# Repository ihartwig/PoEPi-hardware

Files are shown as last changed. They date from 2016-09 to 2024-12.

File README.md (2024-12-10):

Raspberry Pi Zero PoE - PoEPi
=============================

This repository houses multiple designs for a PoE hat for RPi Zero that combines a 802.3af compliant controller with a 10Mbps ethernet controller/phy to provide power and connectivity over the same cable. The board shape matches RPi Zero, but this board should work on RPi 1/2/3 with 40-pin GPIO and the right headers. Footprints for the RPi Hat EEPROM are present but untested.

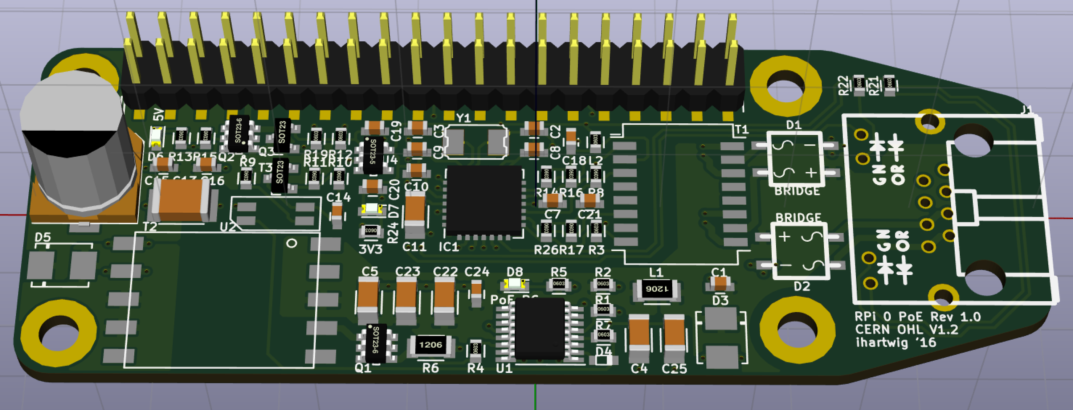
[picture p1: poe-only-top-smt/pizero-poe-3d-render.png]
PoEPi 3D render


## Features
* 5V 12.95W 802.3af-compliant PoE with LTC4267
* 10Mbps ethernet using ENC28J60 (includes Raspbian driver support)

## Variations

* **passive-poe-only-top-smt**: Schematic only (layout abandoned) for an FRC Passive PoE (4-18V) variant using a TPS63070 buck-boost regulator
  * Ported sch, pcb, and libs to KiCAD 7.0.2
  * New project at https://github.com/ihartwig/ether-friends/tree/main/pizero-papoe
* **poe-only-top-smt**: Rev 2 with only PoE parts and all parts on top for easy automated assembly.
  * [Order bare pcbs from Dirty PCB](http://dirtypcbs.com/view.php?share=26685&accesskey=).
  * Known issues:
    * J1 TPIN+/- pair is on the wrong pins - no link up
    * PoE negotiation does not complete
* **servo-controller**: Rev 1 with buffered output to drive 3 servos.
* **speaker-amplifier**: Rev 1 with an amplifier for the RPi's PWM audio output.
* **ws2812-controller**: Rev 1 with a connector for NeoPixels.

## Raspberry Pi Zero - PoEPi

The Raspberry Pi Zero is a low power and low footprint Raspberry Pi. It gives people an opportunity to move towards compact connected devices
while moving away from being a just a small computer. PiPoE adds a new way of connecting the Raspberry Pi Zero with the world in a very efficient
manner. Power over Ethernet is a way if injecting power into an Ethernet cable without interfering with the data. What it gives you is a high 
reliability way of powering and communicating with the Raspberry Pi. The design of PoEPi is open source under the CERN OHL V1.2 and can be easily
adapted to your own custom designs. 

For more information check out the Wiki on github

### Basic Hardware usage

1. Setup your Raspberry Pi with a monitor and enable SSH with raspi-config
2. Plug Ethernet cable into a PoE switch or add a PoE injector somehwhere in you Ethernet line
3. Connect the PoEPi to the Raspberry Pi
4. Plug in the "injected" Ethernet cable
5. The Pi Zero should be powered and you then SSH into the Pi

For information on the particular PoEPi modules and how to control them please see the wiki on the github page

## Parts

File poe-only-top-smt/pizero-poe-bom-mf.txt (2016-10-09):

Designator	X-Loc	Y-Loc	Rotation	Side	Type	X-Size	Y-Size	Value	Footprint	Populate	MPN
C1	55.5	-22.25	180	top	SMT	2	1	0.1uf 100V	Capacitors_SMD:C_0603	1	CL10B104KC8NNNC
C10	29.25	-12.25	180	top	SMT	2	1	0.1uf	Capacitors_SMD:C_0603	1	
C11	29.25	-16	90	top	SMT	2	1	10uf	Capacitors_SMD:C_1206	1	
C12	3.25	-14.25	270	top	SMT	2	1	470uF	Capacitors_SMD:c_elec_8x10	1	UWT1A471MNL1GS
C13	22	-12.5	0	top	SMT	2	1	2.2nF 250Vac	Capacitors_SMD:C_0603	1	C1608C0G2E222J080AA
C14	11.25	-15.25	90	top	SMT	2	1	6.8nf	Capacitors_SMD:C_0603	1	
C15	7.25	-15.25	270	top	SMT	2	1	0.1uF	Capacitors_SMD:C_0603	1	
C16	9.25	-15.25	270	top	SMT	2	1	0.1uF	Capacitors_SMD:C_0603	1	
C17	43.25	-8	0	bottom	nostuff	2	1	nostuff-0.1u	Capacitors_SMD:C_0603	0	
C18	42.75	-9	270	top	SMT	2	1	0.1uf	Capacitors_SMD:C_0603	1	
C19	16.75	-8.75	270	top	SMT	2	1	1uF	Capacitors_SMD:C_0603	1	
C2	40	-8	180	top	SMT	2	1	16pf	Capacitors_SMD:C_0603	1	
C20	22.75	-8.75	270	top	SMT	2	1	1uF	Capacitors_SMD:C_0603	1	
C21	44.25	-14.75	0	top	SMT	2	1	0.1uf	Capacitors_SMD:C_0603	1	
C22	33.75	-23.75	90	top	SMT	2	1	2.2uF 100V	Capacitors_SMD:C_1206	1	GRM31CR72A225KA73L
C23	30.75	-23.75	90	top	SMT	2	1	2.2uF 100V	Capacitors_SMD:C_1206	1	GRM31CR72A225KA73L
C24	36.25	-23	90	top	SMT	2	1	0.1uF 100V	Capacitors_SMD:C_0603	1	CL10B104KC8NNNC
C25	51.75	-27	270	top	SMT	2	1	2.2uF 100V	Capacitors_SMD:C_1206	1	GRM31CR72A225KA73L
C3	30.5	-8	0	top	SMT	2	1	16pf	Capacitors_SMD:C_0603	1	
C4	49	-27	270	top	SMT	2	1	2.2uF 100V	Capacitors_SMD:C_1206	1	GRM31CR72A225KA73L
C5	27.75	-23.75	90	top	SMT	2	1	2.2uF 100V	Capacitors_SMD:C_1206	1	GRM31CR72A225KA73L
C7	41.25	-14.75	0	top	SMT	2	1	0.1uf	Capacitors_SMD:C_0603	1	
C8	40	-10	0	top	SMT	2	1	0.1uf	Capacitors_SMD:C_0603	1	
C9	30.5	-10	180	top	SMT	2	1	0.1uf	Capacitors_SMD:C_0603	1	
D1	61.5	-11	0	top	SMT	2	1	BRIDGE	pizero-poe-special:MBS	1	HD01-T
D2	61.5	-18.5	180	top	SMT	2	1	BRIDGE	pizero-poe-special:MBS	1	HD01-T
D3	55.5	-26.75	270	top	SMT	2	1	SMAJ58A	Diodes_SMD:DO-214BA	1	SMAJ58A
D4	46.25	-28.75	0	top	SMT	2	1	BAS516	pizero-poe-special:sod523	1	"BAS516,115"
D5	3.25	-20.5	0	top	SMT	2	1	SBM1040	Diodes_SMD:DO-214BA	1	RB058L150TE25
D6	1.25	-8.75	270	top	SMT	2	1	LED Green	LEDs:LED_0603	1	LTST-C190GKT
D7	24.75	-8.75	90	top	SMT	2	1	LED Green	LEDs:LED_0603	1	LTST-C190GKT
D8	39.25	-22.25	180	top	SMT	2	1	LED Green	LEDs:LED_0603	1	LTST-C190GKT
IC1	35.25	-14.75	90	top	SMT	2	1	ENC28J60-I/ML	Housings_DFN_QFN:QFN-28-1EP_6x6mm_Pitch0.65mm	1	ENC28J60-I/ML
J1					nostuff	2	1	RJ45-LED	w_conn_pc:rj45-tyco-2-406549-7	0	RJHSE-5081
L1	50.5	-22.75	180	top	SMT	2	1	2.2uH	Resistors_SMD:R_1206	1	LQM2HPN2R2MEHL
L2	44.75	-9	90	top	SMT	2	1	BEAD	Resistors_SMD:R_0603	1	
P2					nostuff	2	1	dnp-REF-182665-01	pizero-poe-special:Pin_Header_Straight_TH-SMT-NoPaste_2x20	0	
Q1	28.5	-27.75	0	top	SMT	2	1	SI3440DV	TO_SOT_Packages_SMD:SOT-23-6	1	SI3440DV-T1-E3
Q2	8.25	-8.75	180	top	SMT	2	1	DMMT3906_Dual_PNP	TO_SOT_Packages_SMD:SOT-23-6	1	DMMT3906-7-F
Q3	12	-8.75	180	top	SMT	2	1	Q_PMOS_GSD	TO_SOT_Packages_SMD:SOT-23	1	DMP3099L-7
R1	46.25	-24.5	0	top	nostuff	2	1	nostuff	Resistors_SMD:R_0603	0	
R10	11.25	-12	270	top	SMT	2	1	10k	Resistors_SMD:R_0603	1	
R11	7.25	-12	270	top	SMT	2	1	10k	Resistors_SMD:R_0603	1	
R12	9.25	-12	90	top	SMT	2	1	3.3k	Resistors_SMD:R_0603	1	
R13	3.25	-8.75	270	top	SMT	2	1	1k	Resistors_SMD:R_0603	1	
R14	40.75	-12.25	270	top	SMT	2	1	49.9	Resistors_SMD:R_0603	1	
R15	5.25	-8.75	270	top	SMT	2	1	10k	Resistors_SMD:R_0603	1	
R16	42.75	-12.25	270	top	SMT	2	1	49.9	Resistors_SMD:R_0603	1	
R17	42.75	-17.25	270	top	SMT	2	1	49.9	Resistors_SMD:R_0603	1	
R18	37.75	-8	0	bottom	nostuff	2	1	nostuff-1k	Resistors_SMD:R_0603	0	
R19	14.75	-8.75	270	top	SMT	2	1	47k	Resistors_SMD:R_0603	1	
R2	46.25	-22.25	0	top	SMT	2	1	10k	Resistors_SMD:R_0603	1	
R20	37.75	-12	0	bottom	nostuff	2	1	nostuff-3.9k	Resistors_SMD:R_0603	0	
R21	70	-3.5	90	top	SMT	2	1	549	Resistors_SMD:R_0603	1	
R22	67.5	-3.5	90	top	SMT	2	1	549	Resistors_SMD:R_0603	1	
R23	37.75	-10	0	bottom	nostuff	2	1	nostuff-3.9k	Resistors_SMD:R_0603	0	
R24	26.75	-8.75	90	top	SMT	2	1	220	Resistors_SMD:R_0603	1	
R26	40.75	-17.25	270	top	SMT	2	1	49.9	Resistors_SMD:R_0603	1	
R3	44.75	-17.25	90	top	SMT	2	1	1k	Resistors_SMD:R_0603	1	
R4	36.25	-28	90	top	SMT	2	1	10k	Resistors_SMD:R_0603	1	
R5	42.75	-22.25	0	top	SMT	2	1	23k	Resistors_SMD:R_0603	1	
R6	32.75	-27.75	0	top	SMT	2	1	0.05	Resistors_SMD:R_1206	1	CSNL1206FT50L0
R7	46.25	-26.75	0	top	SMT	2	1	6.8k	Resistors_SMD:R_0603	1	
R8	44.75	-12.25	270	top	SMT	2	1	2.32k	Resistors_SMD:R_0603	1	
R9	13.25	-12	270	top	SMT	2	1	1k	Resistors_SMD:R_0603	1	
T1	51.5	-13.75	0	top	SMT	2	1	H2019FNL	pizero-poe-special:Transformer_Pulse_H2019FNL	1	749013011A
T2	16.75	-23.5	90	top	SMT	2	1	TRANSFO	project_foot:PoE_TRANS	1	7491199501
T3	14	-15.25	90	top	SMT	2	1	VOLTAGE_REF	TO_SOT_Packages_SMD:SOT-23	1	TLV431BSN1T1G
U1	41.25	-26.5	180	top	SMT	2	1	LTC4267	Housings_SSOP:QSOP-16_3.9x4.9mm_Pitch0.635mm	1	LTC4267CGN#PBF
U2	20.5	-15.25	270	top	SMT	2	1	PS2911-1-K-AX	project_foot:OPTO_ISO	1	PS2911-1-K-AX
U3	43.25	-11	180	bottom	nostuff	2	1	nostuff-AT24CS32-SSHM	Housings_SSOP:TSSOP-8_4.4x3mm_Pitch0.65mm	0	
U4	19.75	-8.75	0	top	SMT	2	1	AP7365_SOT-23-5	TO_SOT_Packages_SMD:SOT-23-5	1	AP7365-33WG-7
W1					nostuff	2	1	TEST_1P	Measurement_Points:Measurement_Point_Round-SMD-Pad_Small	0	
W2					nostuff	2	1	TEST_1P	Measurement_Points:Measurement_Point_Round-SMD-Pad_Small	0	
Y1	35.25	-9	180	top	SMT	2	1	25Mhz	w_crystal:crystal_smd_5x3.2mm	1	445I23D25M00000

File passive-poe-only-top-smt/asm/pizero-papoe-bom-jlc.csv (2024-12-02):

Comment | Designator | Footprint | LCSC
0.1uf 100V | C1 | Capacitor_SMD:C_0603_1608Metric
10uf | C11 | Capacitor_SMD:C_1206_3216Metric
470uF | C12 | Capacitor_SMD:CP_Elec_8x10
0.1uF | C15,C16 | Capacitor_SMD:C_0603_1608Metric
nostuff-0.1u | C17 | Capacitor_SMD:C_0603_1608Metric
1uF | C19,C20 | Capacitor_SMD:C_0603_1608Metric
16pf | C2,C3 | Capacitor_SMD:C_0603_1608Metric
0.1uf | C7,C8,C9,C10,C18,C21 | Capacitor_SMD:C_0603_1608Metric
BRIDGE | D1,D2 | pizero-poe-special:MBS | C52151
SMAJ58A | D3 | Diode_SMD:D_SMA
LED Green | D6,D7 | LED_SMD:LED_0603_1608Metric
hole-metalized-no4 | H1,H2,H3,H4 | pizero-poe-special:hole-m3
RJ45-LED | J1 | pizero-poe-special:rj45-tyco-2-406549-7
1.5uH 4.6A Isat | L1
BEAD | L2 | Resistor_SMD:R_0603_1608Metric
dnp-REF-182665-01 | P2 | pizero-poe-special:Pin_Header_Straight_TH-SMT-NoPaste_2x20
DMMT3906_Dual_PNP | Q2 | Package_TO_SOT_SMD:SOT-23-6 | C526572
Q_PMOS_GSD | Q3 | Package_TO_SOT_SMD:SOT-23 | C155244
R_Small | R1,R2,R4,R5
49.9 | R14,R16,R17,R26 | Resistor_SMD:R_0603_1608Metric
10k | R15 | Resistor_SMD:R_0603_1608Metric
nostuff-1k | R18 | Resistor_SMD:R_0603_1608Metric
47k | R19 | Resistor_SMD:R_0603_1608Metric
nostuff-3.9k | R20,R23 | Resistor_SMD:R_0603_1608Metric
549 | R21,R22 | Resistor_SMD:R_0603_1608Metric
220 | R24 | Resistor_SMD:R_0603_1608Metric
1k | R3,R13 | Resistor_SMD:R_0603_1608Metric
2.32k | R8 | Resistor_SMD:R_0603_1608Metric
H2019FNL | T1 | pizero-poe-special:Transformer_Pulse_H2019FNL | C7193798
ENC28J60-I/ML | U1 | Package_DFN_QFN:QFN-28-1EP_6x6mm_P0.65mm_EP4.25x4.25mm | C629417
TPS63070RNMR | U2 | TPS63070RNMR:VREG_TPS63070RNMR | C109322
nostuff-AT24CS32-SSHM | U3 | Package_SO:TSSOP-8_4.4x3mm_P0.65mm
AP7365_SOT-23-5 | U4 | Package_TO_SOT_SMD:SOT-23-5 | C150742
TEST_1P | W1,W2 | TestPoint:TestPoint_Pad_D1.0mm
25Mhz | Y1 | Crystal:Crystal_SMD_5032-2Pin_5.0x3.2mm

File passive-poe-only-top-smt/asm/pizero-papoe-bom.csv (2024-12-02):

Source: | /Users/ihartwig/repos/PoEPi-hardware/passive-poe-only-top-smt/pizero-papoe.kicad_sch
Date: | 2024 December 01, Sunday 01:49:08
Tool: | Eeschema 7.0.2-0
Generator: | /Applications/KiCad-7/KiCad.app/Contents/SharedSupport/plugins/bom_csv_grouped_by_value.py
Component Count: | 53
Collated Components:
Item | Qty | Reference(s) | Value | LibPart | Footprint | Datasheet | DNP | Alt Mfg | Alt Mfg Part No | Availability | Check_prices | Description | Digikey Part No | MANUFACTURER | MF | MP | Mfg | Mfg Part No | Mouser Part No. | PARTREV | Package | Price | STANDARD | SnapEDA_Link | Type
1 | 1 | C1 | 0.1uf 100V | pizero-papoe-rescue:C | Capacitor_SMD:C_0603_1608Metric |  |  |  |  |  |  | 0.10µF 100V Ceramic Capacitor X7R 0603 | 1276-6807-1-ND |  |  |  | Samsung | CL10B104KC8NNNC |  |  |  |  |  |  | SMT
2 | 2 | C2, C3 | 16pf | pizero-papoe-rescue:C | Capacitor_SMD:C_0603_1608Metric |  |  |  |  |  |  |  |  |  |  |  |  |  |  |  |  |  |  |  | SMT
3 | 6 | C7, C8, C9, C10, C18, C21 | 0.1uf | pizero-papoe-rescue:C | Capacitor_SMD:C_0603_1608Metric |  |  |  |  |  |  |  |  |  |  |  |  |  |  |  |  |  |  |  | SMT
4 | 1 | C11 | 10uf | pizero-papoe-rescue:C | Capacitor_SMD:C_1206_3216Metric |  |  |  |  |  |  |  |  |  |  |  |  |  |  |  |  |  |  |  | SMT
5 | 1 | C12 | 470uF | pizero-papoe-rescue:CP | Capacitor_SMD:CP_Elec_8x10 |  |  |  |  |  |  | 470µF 10V Aluminum Capacitors Radial, Can - SMD | 493-2169-1-ND |  |  |  | Nichicon | UWT1A471MNL1GS |  |  |  |  |  |  | SMT
6 | 2 | C15, C16 | 0.1uF | pizero-papoe-rescue:C | Capacitor_SMD:C_0603_1608Metric |  |  |  |  |  |  |  |  |  |  |  |  |  |  |  |  |  |  |  | SMT
7 | 1 | C17 | nostuff-0.1u | pizero-papoe-rescue:C_Small | Capacitor_SMD:C_0603_1608Metric |  |  |  |  |  |  |  |  |  |  |  |  |  |  |  |  |  |  |  | nostuff
8 | 2 | C19, C20 | 1uF | pizero-papoe-rescue:C_Small | Capacitor_SMD:C_0603_1608Metric |  |  |  |  |  |  |  |  |  |  |  |  |  |  |  |  |  |  |  | SMT
9 | 2 | D1, D2 | BRIDGE | pizero-papoe-rescue:BRIDGE | pizero-poe-special:MBS |  |  |  |  |  |  | Bridge Rectifier Single Phase 100V 800mA Surface Mount 4-MiniDIP | HD01DICT-ND |  |  |  | Diodes Inc | HD01-T |  |  |  |  |  |  | SMT
10 | 1 | D3 | SMAJ58A | pizero-papoe-rescue:ZENER | Diode_SMD:D_SMA |  |  |  |  |  |  | TVS DIODE 58VWM 93.6VC SMA | SMAJ58ALFCT-ND |  |  |  | Littelfuse | SMAJ58A | 576-SMAJ58A |  |  |  |  |  | SMT
11 | 2 | D6, D7 | LED Green | pizero-papoe-rescue:Led_Small | LED_SMD:LED_0603_1608Metric |  |  |  |  |  |  | LED GREEN CLEAR 0603 SMD | 160-1183-1-ND |  |  |  | Lite-On | LTST-C190GKT |  |  |  |  |  |  | SMT
12 | 4 | H1, H2, H3, H4 | hole-metalized-no4 | pizero-papoe-rescue:hole-metalized-no4 | pizero-poe-special:hole-m3 |  |  |  |  |  |  |  |  |  |  |  |  |  |  |  |  |  |  |  | nostuff
13 | 1 | J1 | RJ45-LED | pizero-papoe-rescue:RJ45-LED | pizero-poe-special:rj45-tyco-2-406549-7 |  |  |  |  |  |  | Jack Modular Connector 8p8c (RJ45, Ethernet) 90° Angle (Right) Unshielded | RJHSE-5081-ND |  |  |  | Amphenol | RJHSE-5081 |  |  |  |  |  |  | TH
14 | 1 | L2 | BEAD | pizero-papoe-rescue:INDUCTOR | Resistor_SMD:R_0603_1608Metric |  |  |  |  |  |  | FERRITE BEAD 1 KOHM 0603 1LN | 587-1867-1-ND |  |  |  | Taiyo Yuden | BK1608HS102-T |  |  |  |  |  |  | SMT
15 | 1 | P2 | dnp-REF-182665-01 | pizero-papoe-rescue:CONN_02X20 | pizero-poe-special:Pin_Header_Straight_TH-SMT-NoPaste_2x20 |  |  |  |  |  |  |  |  |  |  |  |  |  |  |  |  |  |  |  | nostuff
16 | 1 | Q2 | DMMT3906_Dual_PNP | pizero-papoe-rescue:DMMT3906_Dual_PNP | Package_TO_SOT_SMD:SOT-23-6 |  |  |  |  |  |  | TRANS 2PNP 40V 0.2A SOT26 | DMMT3906-7-FDICT-ND |  |  |  | Diodes Inc | DMMT3906-7-F |  |  |  |  |  |  | SMT
17 | 1 | Q3 | Q_PMOS_GSD | pizero-papoe-rescue:Q_PMOS_GSD | Package_TO_SOT_SMD:SOT-23 |  |  |  |  |  |  | MOSFET P-CH 30V SOT23 | DMP3099L-7DICT-ND |  |  |  | Diodes Inc | DMP3099L-7 |  |  |  |  |  |  | SMT
18 | 1 | R3 | 1k | pizero-papoe-rescue:R | Resistor_SMD:R_0603_1608Metric |  |  |  |  |  |  |  |  |  |  |  |  |  |  |  |  |  |  |  | SMT
19 | 1 | R8 | 2.32k | pizero-papoe-rescue:R | Resistor_SMD:R_0603_1608Metric |  |  |  |  |  |  |  |  |  |  |  |  |  |  |  |  |  |  |  | SMT
20 | 1 | R13 | 1k | pizero-papoe-rescue:R_Small | Resistor_SMD:R_0603_1608Metric |  |  |  |  |  |  |  |  |  |  |  |  |  |  |  |  |  |  |  | SMT
21 | 4 | R14, R16, R17, R26 | 49.9 | pizero-papoe-rescue:R | Resistor_SMD:R_0603_1608Metric |  |  |  |  |  |  |  |  |  |  |  |  |  |  |  |  |  |  |  | SMT
22 | 1 | R15 | 10k | pizero-papoe-rescue:R_Small | Resistor_SMD:R_0603_1608Metric |  |  |  |  |  |  |  |  |  |  |  |  |  |  |  |  |  |  |  | SMT
23 | 1 | R18 | nostuff-1k | pizero-papoe-rescue:R_Small | Resistor_SMD:R_0603_1608Metric |  |  |  |  |  |  |  |  |  |  |  |  |  |  |  |  |  |  |  | nostuff
24 | 1 | R19 | 47k | pizero-papoe-rescue:R_Small | Resistor_SMD:R_0603_1608Metric |  |  |  |  |  |  |  |  |  |  |  |  |  |  |  |  |  |  |  | SMT
25 | 2 | R20, R23 | nostuff-3.9k | pizero-papoe-rescue:R_Small | Resistor_SMD:R_0603_1608Metric |  |  |  |  |  |  |  |  |  |  |  |  |  |  |  |  |  |  |  | nostuff
26 | 2 | R21, R22 | 549 | pizero-papoe-rescue:R | Resistor_SMD:R_0603_1608Metric |  |  |  |  |  |  |  |  |  |  |  |  |  |  |  |  |  |  |  | SMT
27 | 1 | R24 | 220 | pizero-papoe-rescue:R_Small | Resistor_SMD:R_0603_1608Metric |  |  |  |  |  |  |  |  |  |  |  |  |  |  |  |  |  |  |  | SMT
28 | 1 | T1 | H2019FNL | pizero-papoe-rescue:H2019FNL | pizero-poe-special:Transformer_Pulse_H2019FNL |  |  | Pulse Electronics | H2019FNL |  |  | TRANS WE-LAN 10/100 POE SMD | 732-7063-1-ND |  |  |  | Wurth Electronics Inc | 749013011A |  |  |  |  |  |  | SMT
29 | 1 | U1 | ENC28J60-I/ML | pizero-papoe-rescue:ENC28J60-I/ML | Package_DFN_QFN:QFN-28-1EP_6x6mm_P0.65mm_EP4.25x4.25mm |  |  |  |  |  |  |  | ENC28J60-I/ML-ND |  |  |  | Microchip Technology | ENC28J60-I/ML |  |  |  |  |  |  | SMT
30 | 1 | U2 | ISL85410FRZ-T | pizero-papoe-special:ISL85410FRZ-T | pizero-poe-special:ISL85410FRZ-T_SON50P300X300X100-13N_270X200_ |  |  |  |  | In Stock | https://www.snapeda.com/parts/ISL85410FRZ-T/Intersil/view-part/?ref=eda | Buck Switching Regulator IC Positive Adjustable 0.6V 1 Output 1A 12-VFDFN Exposed Pad |  | RENESAS | Intersil | ISL85410FRZ-T |  |  |  | 8.00 | DFN-12 Intersil | None | IPC-7351B | https://www.snapeda.com/parts/ISL85410FRZ-T/Intersil/view-part/?ref=snap
31 | 1 | U3 | nostuff-AT24CS32-SSHM | pizero-papoe-rescue:AT24CS32-SSHM | Package_SO:TSSOP-8_4.4x3mm_P0.65mm |  |  |  |  |  |  |  |  |  |  |  |  |  |  |  |  |  |  |  | nostuff
32 | 1 | U4 | AP7365_SOT-23-5 | pizero-papoe-rescue:AP7365_SOT-23-5 | Package_TO_SOT_SMD:SOT-23-5 |  |  |  |  |  |  | Linear Voltage Regulator IC Positive Fixed 1 Output 3.3V 600mA SOT-25 | AP7365-33WG-7DICT-ND |  |  |  | Diodes Inc | AP7365-33WG-7 |  |  |  |  |  |  | SMT
33 | 2 | W1, W2 | TEST_1P | pizero-papoe-rescue:TEST_1P | TestPoint:TestPoint_Pad_D1.0mm |  |  |  |  |  |  |  |  |  |  |  |  |  |  |  |  |  |  |  | nostuff
34 | 1 | Y1 | 25Mhz | pizero-papoe-rescue:Crystal | Crystal:Crystal_SMD_5032-2Pin_5.0x3.2mm |  |  |  |  |  |  |  | CTX1175CT-ND |  |  |  | CTS Frequency Controls | 445I23D25M00000 | 774-445I23D25M00000 |  |  |  |  |  | SMT

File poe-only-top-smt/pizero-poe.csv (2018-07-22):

Component | Description | Part | References | Value | Footprint | Quantity Per PCB | Datasheet | Type | Digikey Part No | Mfg | Mfg Part No | Alt Mfg | Alt Mfg Part No | Mouser Part No.
1 | Unpolarized capacitor | C | C7 C8 C9 C10 C15 C16 C18 C21 | 0.1uf | C_0603 | 8 |  | SMT | 311-1088-1-ND
2 | Unpolarized capacitor | C | C1 C24 | 0.1uf 100V | C_0603 | 2 |  | SMT | 1276-6807-1-ND | Samsung | CL10B104KC8NNNC
3 | Unpolarized capacitor | C | C11 | 10uf | C_1206 | 1 |  | SMT | 311-2007-1-ND
4 | Unpolarized capacitor | C | C2 C3 | 16pf | C_0603 | 2 |  | SMT | 490-1408-1-ND
5 | Unpolarized capacitor | C_Small | C19 C20 | 1uF | C_0603 | 2 |  | SMT | 490-1536-1-ND
6 | Unpolarized capacitor | C | C13 | 2.2nF 250Vac | C_1812 | 1 |  | SMT | 490-3492-1-ND | Murata | GA343QR7GD222KW01L | Wurth Electronics | 8.85362E+11
7 | Unpolarized capacitor | C | C4 C5 C22 C23 C25 | 2.2uF 100V | C_1206 | 5 |  | SMT | 490-7209-1-ND | Murata Electronics | GRM31CR72A225KA73L
8 | Polarised capacitor | CP | C12 | 470uF | c_elec_8x10 | 1 |  | SMT | 493-2169-1-ND | Nichicon | UWT1A471MNL1GS
9 | Unpolarized capacitor | C | C14 | 6.8nf | C_0603 | 1 |  | SMT | 1276-1185-1-ND
10 | Unpolarized capacitor | C_Small | C17 | nostuff-0.1u | C_0603 | 1 |  | nostuff
11 |  | DIODE | D4 | BAS516 | sod523 | 1 |  | SMT | 568-1603-1-ND | NXP Semiconductors | BAS516,115 |  |  | 771-BAS516-T/R
12 |  | BRIDGE | D1 D2 | BRIDGE | MBS | 2 |  | SMT | HD01DICT-ND | Diodes Inc | HD01-T
13 | Led | Led_Small | D6 D7 D8 | LED Green | LED_0603 | 3 |  | SMT | 160-1183-1-ND | Lite-On | LTST-C190GKT
14 | Diode schottky | D_Schottky | D5 | SBM1040 | DO-214BA | 1 |  | SMT | RB058L150TE25CT-ND | Rohm Semiconductor | RB058L150TE25
15 | Diode zener | ZENER | D3 | SMAJ58A | DO-214BA | 1 |  | SMT | SMAJ58ALFCT-ND | Littelfuse | SMAJ58A |  |  | 576-SMAJ58A
16 |  | hole-metalized-no4 | H1 H2 H3 H4 | hole-metalized-no4 | hole-m3 | 4 |  | nostuff
17 | ENC28J60 Single Chip Ethernet Interface, QFN-28+EP | ENC28J60-I/ML | IC1 | ENC28J60-I/ML | QFN-28-1EP_6x6mm_Pitch0.65mm | 1 | http://ww1.microchip.com/downloads/en/devicedoc/39662a.pdf | SMT | ENC28J60-I/ML-ND | Microchip Technology | ENC28J60-I/ML
18 |  | RJ45-LED | J1 | RJ45-LED | rj45-tyco-2-406549-7 | 1 |  | TH | RJHSE-5081-ND | Amphenol | RJHSE-5081
19 |  | INDUCTOR | L1 | 2.2uH | R_1206 | 1 |  | SMT | 490-10966-1-ND | Murata Electronics | LQM2HPN2R2MEHL |  |  | 81-LQM2HPN2R2MEHL
20 |  | INDUCTOR | L2 | BEAD | R_0603 | 1 |  | SMT | 587-1867-1-ND | Taiyo Yuden | BK1608HS102-T
21 | Connector 02x20 | CONN_02X20 | P2 | dnp-REF-182665-01 | Pin_Header_Straight_TH-SMT-NoPaste_2x20 | 1 |  | nostuff
22 |  | DMMT3906_Dual_PNP | Q2 | DMMT3906_Dual_PNP | SOT-23-6 | 1 |  | SMT | DMMT3906-7-FDICT-ND | Diodes Inc | DMMT3906-7-F
23 | Transistor P-MOSFET (general) | Q_PMOS_GSD | Q3 | Q_PMOS_GSD | SOT-23 | 1 |  | SMT | DMP3099L-7DICT-ND | Diodes Inc | DMP3099L-7
24 |  | SI3440DV | Q1 | SI3440DV | SOT-23-6 | 1 |  | SMT | SI3440DV-T1-E3CT-ND | Vishay Siliconix | SI3440DV-T1-E3 |  |  | 781-SI3440DV-E3
25 | Resistor | R | R6 | 0.05 | R_1206 | 1 |  | SMT | CSNL1206FT50L0CT-ND | Stackpole Electronics | CSNL1206FT50L0 |  |  | 660-UR732BTTD50L0F
26 | Resistor | R | R2 R4 R10 R11 R15 | 10k | R_0603 | 5 |  | SMT | 311-10.0KHRCT-ND
27 | Resistor | R | R3 R9 R13 | 1k | R_0603 | 3 |  | SMT | 311-1.00KHRCT-ND
28 | Resistor | R | R8 | 2.32k | R_0603 | 1 |  | SMT | 311-2.32KHRCT-ND
29 | Resistor | R_Small | R24 | 220 | R_0603 | 1 |  | SMT | 311-220GRCT-ND
30 | Resistor | R_Small | R5 | 23k | R_0603 | 1 |  | SMT | 311-22KGRCT-ND
31 | Resistor | R | R12 | 3.3k | R_0603 | 1 |  | SMT | 311-3.3KGRCT-ND
32 | Resistor | R_Small | R19 | 47k | R_0603 | 1 |  | SMT | 311-47.0KHRCT-ND
33 | Resistor | R | R14 R16 R17 R26 | 49.9 | R_0603 | 4 |  | SMT | 311-49.9HRCT-ND
34 | Resistor | R | R21 R22 | 549 | R_0603 | 2 |  | SMT | 311-560GRCT-ND
35 | Resistor | R | R7 | 6.8k | R_0603 | 1 |  | SMT | 311-6.8KGRCT-ND
36 | Resistor | R_Small | R18 | nostuff-1k | R_0603 | 1 |  | nostuff
37 | Resistor | R_Small | R20 R23 | nostuff-3.9k | R_0603 | 2 |  | nostuff
38 |  | H2019FNL | T1 | H2019FNL | Transformer_Pulse_H2019FNL | 1 |  | SMT | 732-7063-1-ND | Wurth Electronics Inc | 749013011A | Pulse Electronics | H2019FNL
39 |  | POE_TRANS | T2 | TRANSFO | PoE_TRANS | 1 |  | SMT | 553-1983-1-ND | Pulse Electronics | PA1137NLT | Wurth Electronics Inc | 7491199501 | 710-7491199501
40 |  | VOLTAGE_REF | T3 | VOLTAGE_REF | SOT-23 | 1 |  | SMT | TLV431BSN1T1GOSCT-ND | ON Semiconductor | TLV431BSN1T1G |  |  | 863-TLV431BSN1T1G
41 |  | AP7365_SOT-23-5 | U4 | AP7365_SOT-23-5 | SOT-23-5 | 1 |  | SMT | AP7365-33WG-7DICT-ND | Diodes Inc | AP7365-33WG-7
42 |  | LTC4267 | U1 | LTC4267 | QSOP-16_3.9x4.9mm_Pitch0.635mm | 1 |  | SMT | LTC4267CGN-3#PBF-ND | Linear Technology | LTC4267CGN#PBF
43 | MFP 4L, Full Pitch Mini-Flat Random Phase Opto-Triac, Vdrm 250V, Ift 10mA | FODM3012 | U2 | PS2911-1-K-AX | OPTO_ISO | 1 | http://www.fairchildsemi.com/ds/FO/FODM3053.pdf | SMT | PS2911-1-K-AX-ND | CEL | PS2911-1-K-AX |  |  | 551-PS2911-1-K-AX
44 | 32Kb (4096x8) Serial EEPROM with Unique Serial Number, SO8 | AT24CS32-SSHM | U3 | nostuff-AT24CS32-SSHM | TSSOP-8_4.4x3mm_Pitch0.65mm | 1 | http://www.atmel.com/Images/Atmel-8869-SEEPROM-AT24CS32-Datasheet.pdf | nostuff
45 | point | TEST_1P | W1 W2 | TEST_1P | Measurement_Point_Round-SMD-Pad_Small | 2 |  | nostuff
46 | Two pin crystal | Crystal | Y1 | 25Mhz | crystal_smd_5x3.2mm | 1 |  | SMT | CTX1175CT-ND | CTS Frequency Controls | 445I23D25M00000 |  |  | 774-445I23D25M00000
Component Groups: | 47
Component Count: | 79
Fitted Components: | 78
Number of PCBs: | 1
Total components: | 78
Schematic Version: | 0.1d
Schematic Date: | 2/2/16
BoM Date: | Tuesday, October 25, 2016 'PMt' 10:26:28 PM
Schematic Source: | /Users/ihartwig/repos/PoEPi-hardware/poe-only-top-smt/pizero-poe.sch
KiCad Version: | Eeschema 4.0.2-stable

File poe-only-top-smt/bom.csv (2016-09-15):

ref | value | footprint | Mouser Part No. | Quantity
C1 C7 C8 C9 C10 C19 C18 C21 C15 C16 | 0.1uf | w_smd_cap:c_0402 | 710-885012105001 | 10
C11 | 10uf | w_smd_cap:c_0603 | 81-ZRB18AR61C106ME1L | 1
C12 | CP | w_smd_cap:c_elec_4x4.5 | 667-EEE-1AA330WR | 1
C13 | 2nf | w_smd_cap:c_0603 | 81-GRM1885C1H202JA1D | 1
C14 | 6.8nf | w_smd_cap:c_0402 | 81-GRM155R71H682KA8D | 1
C17 | CP | w_smd_cap:c_elec_8x6.5 | 667-EEE-1AA221P | 1
C2 C3 | 16pf | w_smd_cap:c_0402 | 81-GRM1555C1H160JA1D | 2
C20 | 1uf | w_smd_cap:c_0402 | 810-C1005X5R1H104K | 1
C22 | 1uf | w_smd_cap:c_0805 | 810-C2012X7S2A105K | 1
C4 | 220uf | w_smd_cap:c_tant_B | 581-TAJB475K025R | 1
C5 | 6.8uf | w_smd_cap:c_tant_D | 74-293D685X9050D2TE3 | 1
D1 D2 | BRIDGE | w_smd_diode:MBS | 621-HD01-T | 2
D3 | ZENER | w_smd_diode:do214ac | 576-SMAJ58A | 1
D4 | BAS516 | w_smd_diode:sod523 | 771-BAS516-T/R | 1
D5 | D_Schottky | w_smd_diode:do214ab | 621-B360A-F | 1
D6 | LED | w_smd_leds:Led_0603 | 743-HT-191USD | 1
D7 | ZENER | w_smd_diode:sod123 | 771-BZT52HB5V1115 | 1
IC1 | ENC28J60-I/ML | w_smd_qfn:qfn-28 | 579-ENC28J60-I/ML | 1
J1 | RJ45-LED | w_conn_pc:rj45-tyco-2-406549-7 | 710-615008137421 | 1
L1 | 2.2uH | w_smd_inductors:inductor_smd_1008 | 81-LQM2HPN2R2MEHL | 1
L2 | BEAD | w_smd_inductors:inductor_smd_0402 | 81-BLM15AG102SN1D | 1
Q1 | SI3440DV | w_smd_trans:tsot-6 | 781-SI3440DV-E3 | 1
Q2 | BSS138 | w_smd_trans:sot23 | 621-DMG2305UX-13 | 1
Q3 | BSS138 | w_smd_trans:sot23 | 512-BSS138 | 1
R12 | 3.3k | w_smd_resistors:r_0402 | 754-RR0510P-332D | 1
R13 | 390 | w_smd_resistors:r_0402 | 594-MCT06030C3900FP5 | 1
R14 R16 R17 R26 | 49.9 | w_smd_resistors:r_0402 | 660-RK73H1ETQTP49R9F | 4
R15 | 240 | w_smd_resistors:r_0402 | 754-RR0816P-241D | 1
R18 | 360 | w_smd_resistors:r_0402 | 71-CRCW0603316RFKEB | 1
R19 | 10k | w_smd_resistors:r_0402 | 71-CRCW0402-10K-E3 | 1
R2 R4 R10 R11 | 10k | w_smd_resistors:r_0402 | 754-RR0510P-103D | 4
R20 | 47k | w_smd_resistors:r_0402 | 667-ERJ-2RKF4702X | 1
R21 R22 | 549 | w_smd_resistors:r_0402 | 667-ERJ-2RKF5490X | 2
R24 R23 | 14k | w_smd_resistors:r_0402 | 667-ERJ-2RKF1402X | 2
R25 | 100 | w_smd_resistors:r_0402 | 71-CRCW0402-100-E3 | 1
R3 | 1k | w_smd_resistors:r_0402 | 754-RR0510P-102D | 1
R6 | 0.05 | w_smd_resistors:r_1206 | 660-UR732BTTD50L0F | 1
R7 | 6.8k | w_smd_resistors:r_0402 | 754-RR0510P-682D | 1
R8 | 2.32k | w_smd_resistors:r_0402 | 667-ERJ-2RKF2321X | 1
T1 | PULSE_H1197 | project_foot:H2019 | 673-H1197FNL | 1
T2 | TRANSFO | project_foot:PoE_TRANS | 710-7491199501 | 1
T3 | VOLTAGE_REF | w_smd_trans:sot23 | 863-TLV431BSN1T1G | 1
U2 | PAS291 | project_foot:OPTO_ISO | 551-PS2911-1-K-AX | 1
U3 | LM1117IMPX-ADJ | w_smd_trans:sot223 | 926-M1117IMPXADJNOPB | 1
U5 | DMMT5401 | w_smd_trans:sot23-6 | 621-DMMT5401-7-F | 1
Y1 | 25Mhz | w_crystal:crystal_smd_5x3.2mm | 774-445I23D25M00000 | 1

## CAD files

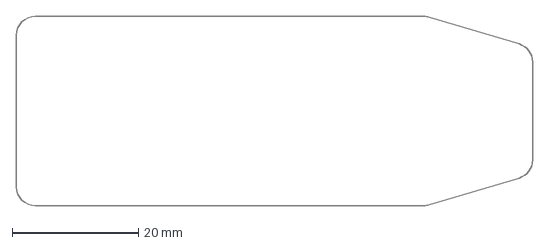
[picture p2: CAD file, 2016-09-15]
poe-only-top-smt/board_edge.dxf
81.8 x 30.0 mm

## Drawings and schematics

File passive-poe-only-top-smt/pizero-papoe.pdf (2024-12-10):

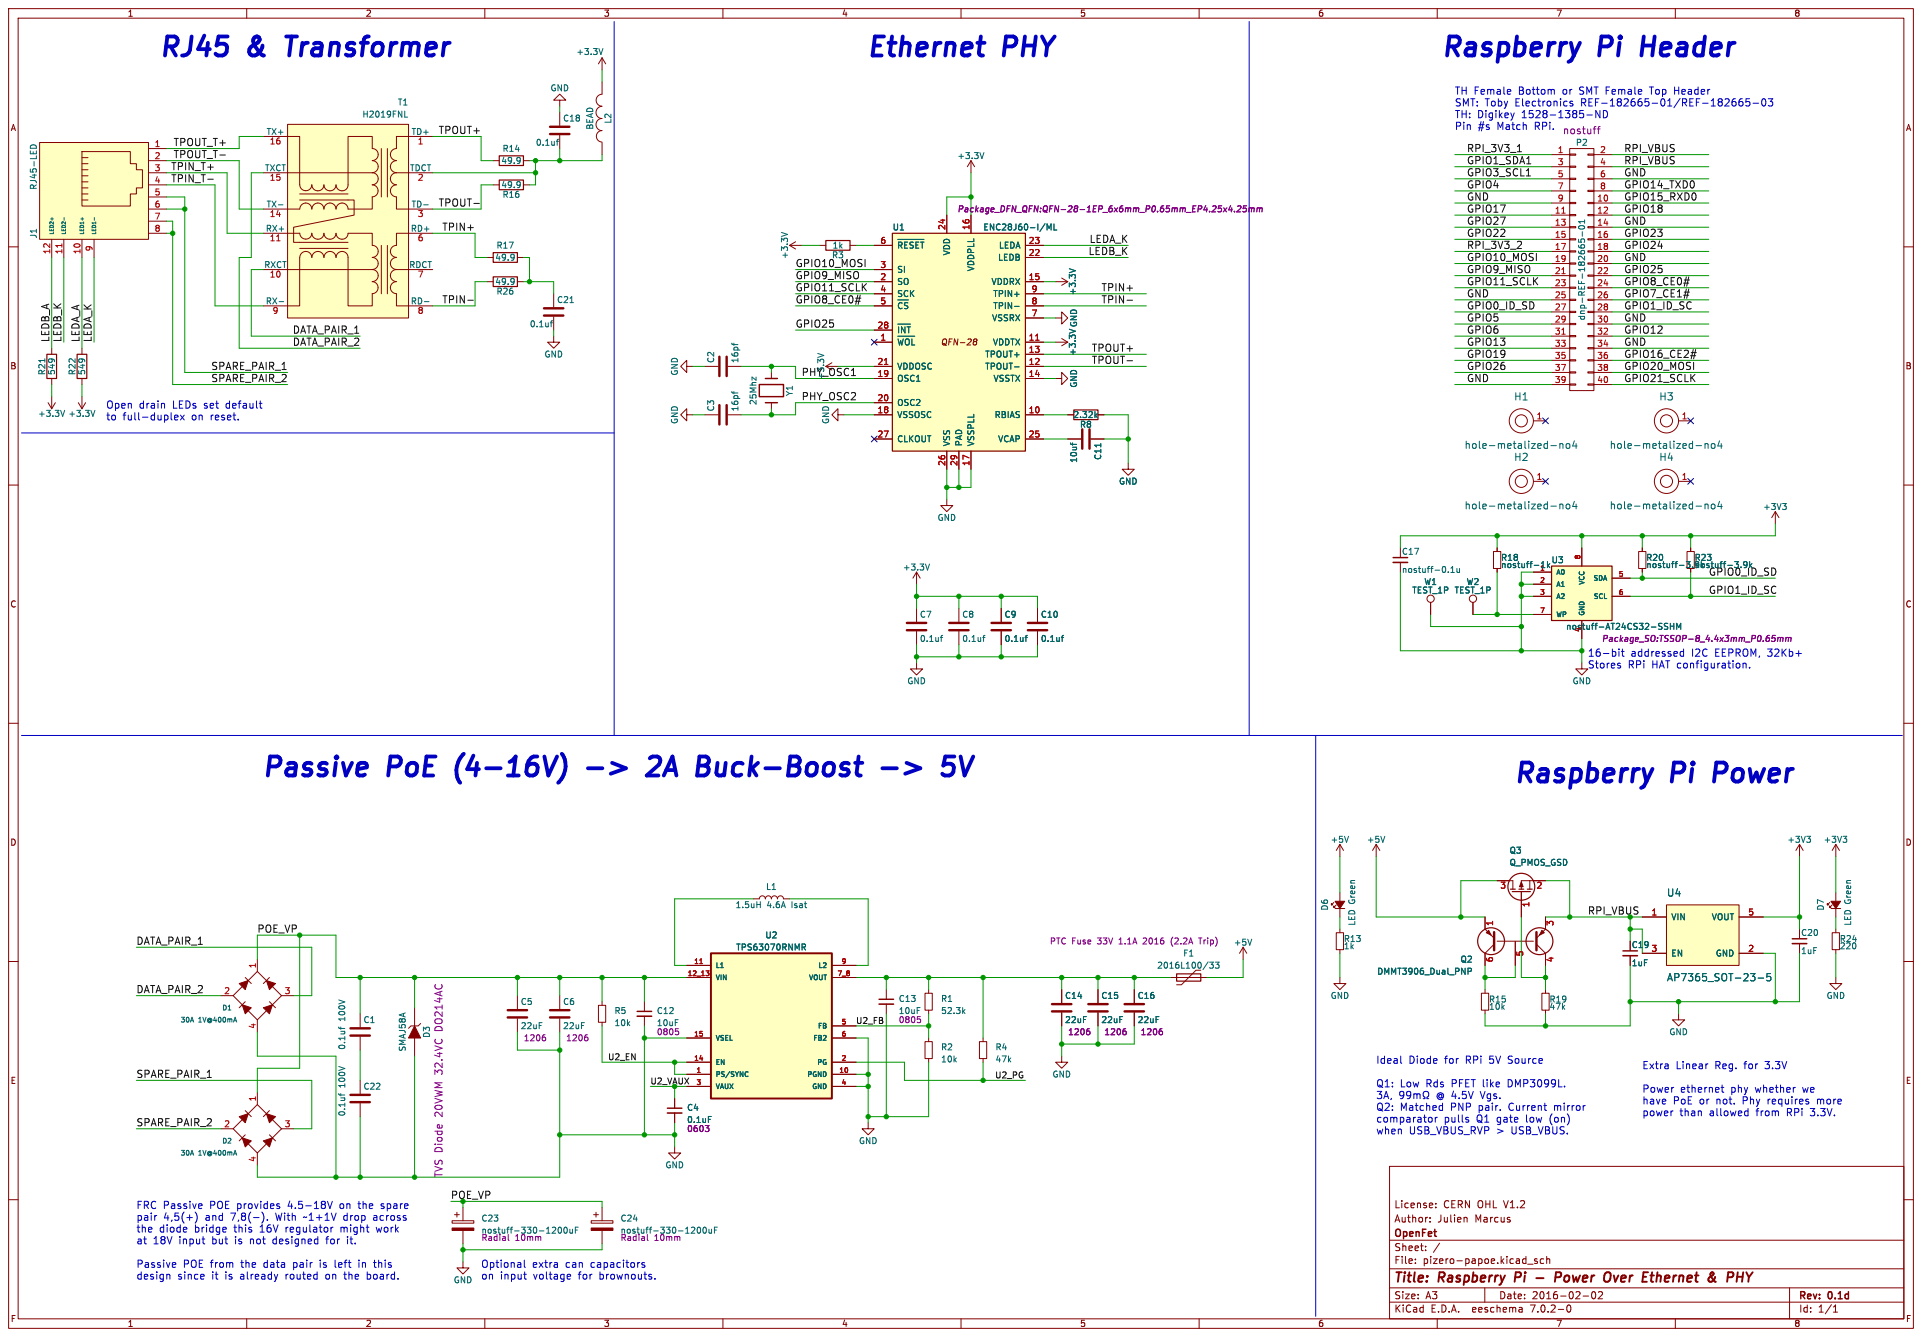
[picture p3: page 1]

Open drain LEDs set default

4 SDA 5 SCL 6 WP 7 VCC

Ideal Diode for RPi 5V Source
Q1: Low Rds PFET like DMP3099L. 3A, þÿ99m©@ 4.5V Vgs.

Power ethernet phy whether we
have PoE or not. Phy requires more

Id: 1/1 Title: Raspberry Pi - Power Over Ethernet & PHY

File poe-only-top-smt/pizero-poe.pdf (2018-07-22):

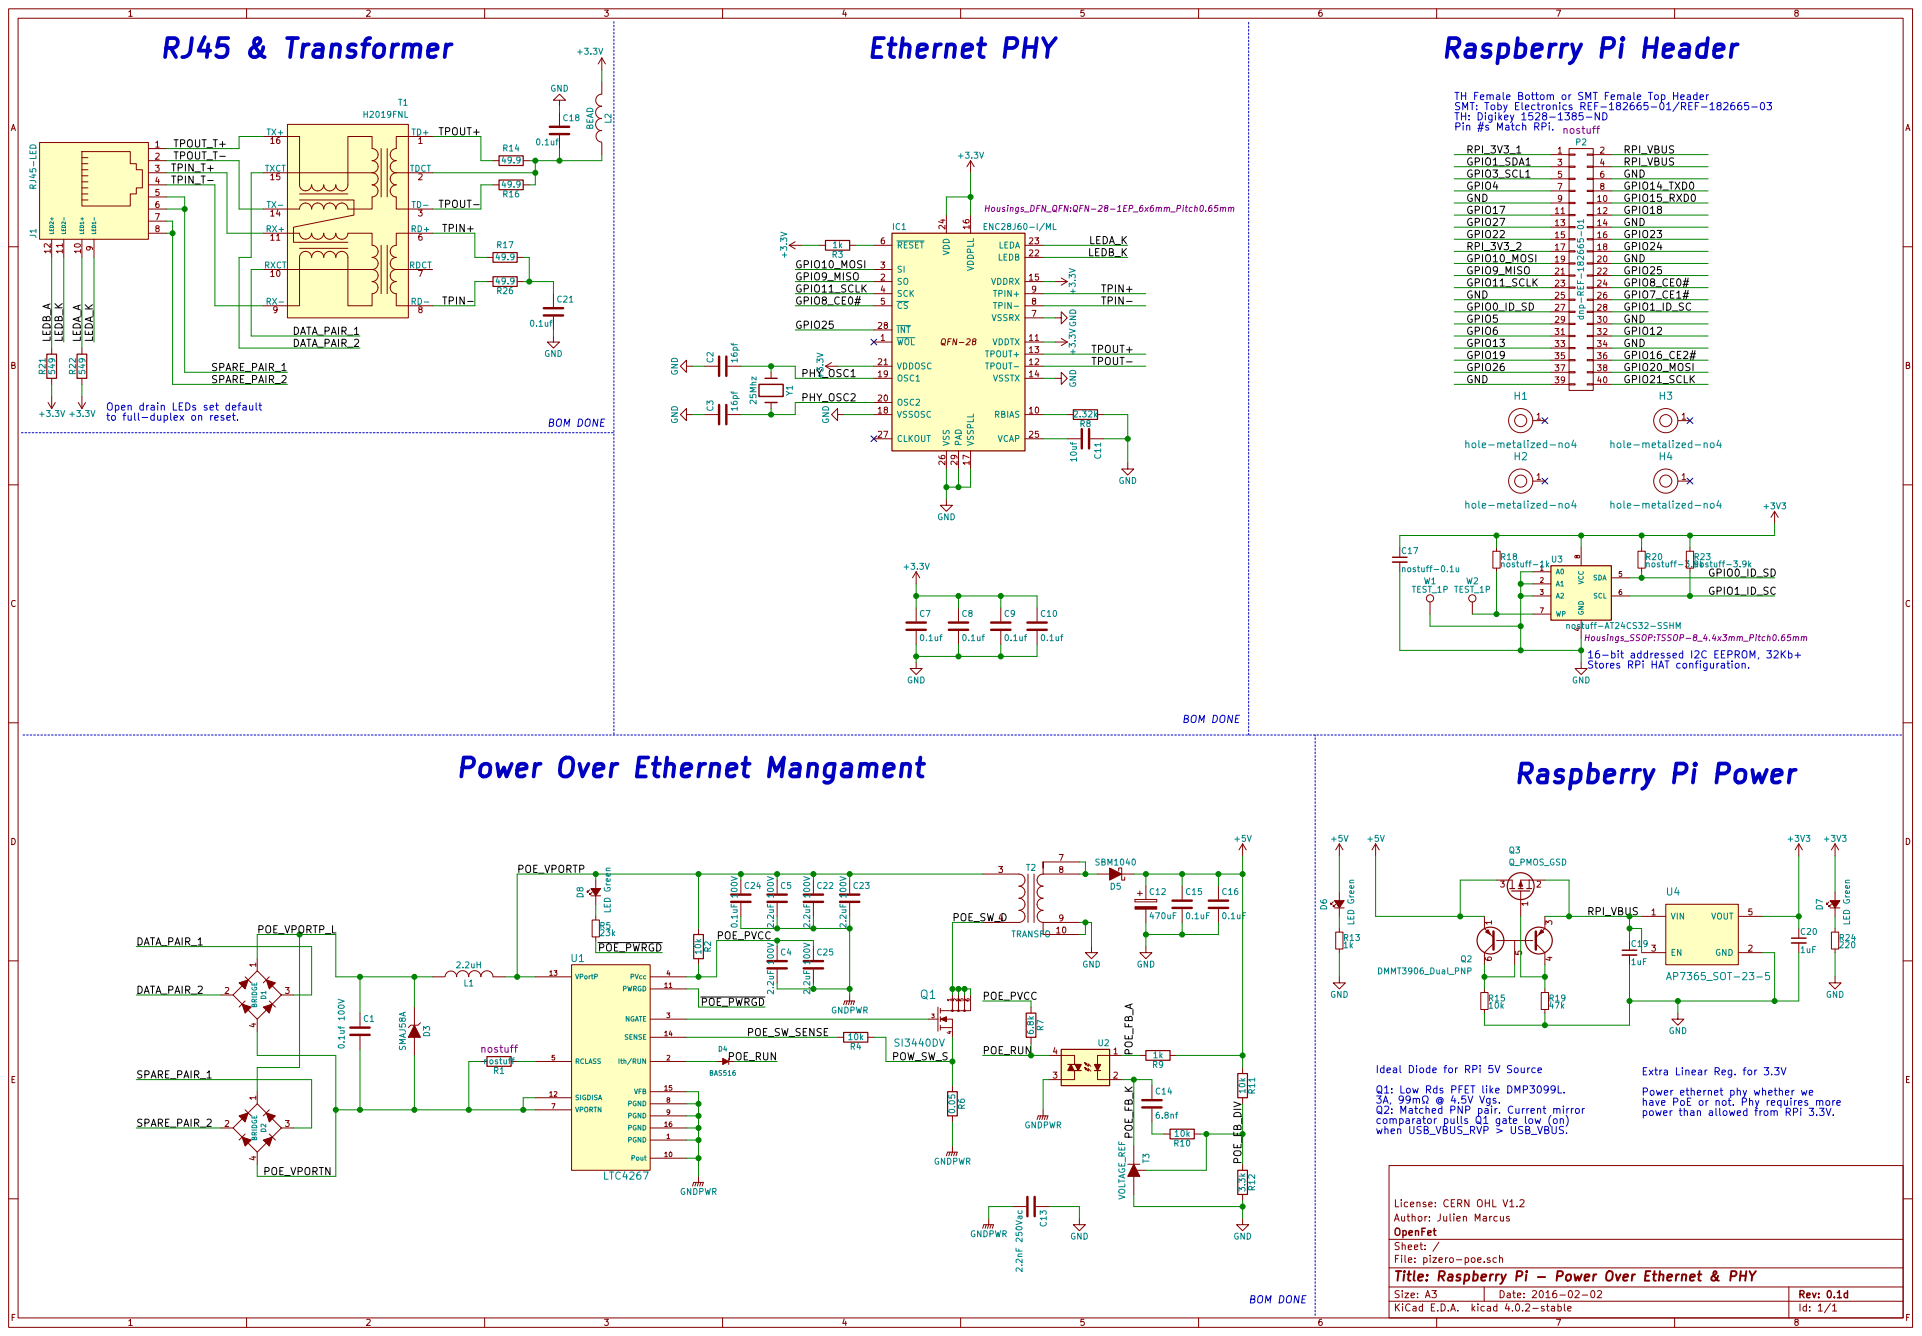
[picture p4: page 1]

TH Female Bottom or SMT Female Top Header
SMT: Toby Electronics REF-182665-01/REF-182665-03
TH: Digikey 1528-1385-ND

2 | TPOUT_T-
3 | TPIN_T+

+3V3 Open drain LEDs set default

hole-metalized-no4
Stores RPi HAT configuration. GND
GND

4 SDA 5 SCL 6 WP 7 VCC

Ideal Diode for RPi 5V Source
Q1: Low Rds PFET like DMP3099L.
3A, 99m @ 4.5V Vgs.
Q2: Matched PNP pair. Current mirror
comparator pulls Q1 gate low (on)

Power ethernet phy whether we
have PoE or not. Phy requires more
power than allowed from RPi 3.3V.

File: pizero-poe.sch Sheet: / OpenFet Author: Julien Marcus License: CERN OHL V1.2

Id: 1/1 Title: Raspberry Pi - Power Over Ethernet & PHY

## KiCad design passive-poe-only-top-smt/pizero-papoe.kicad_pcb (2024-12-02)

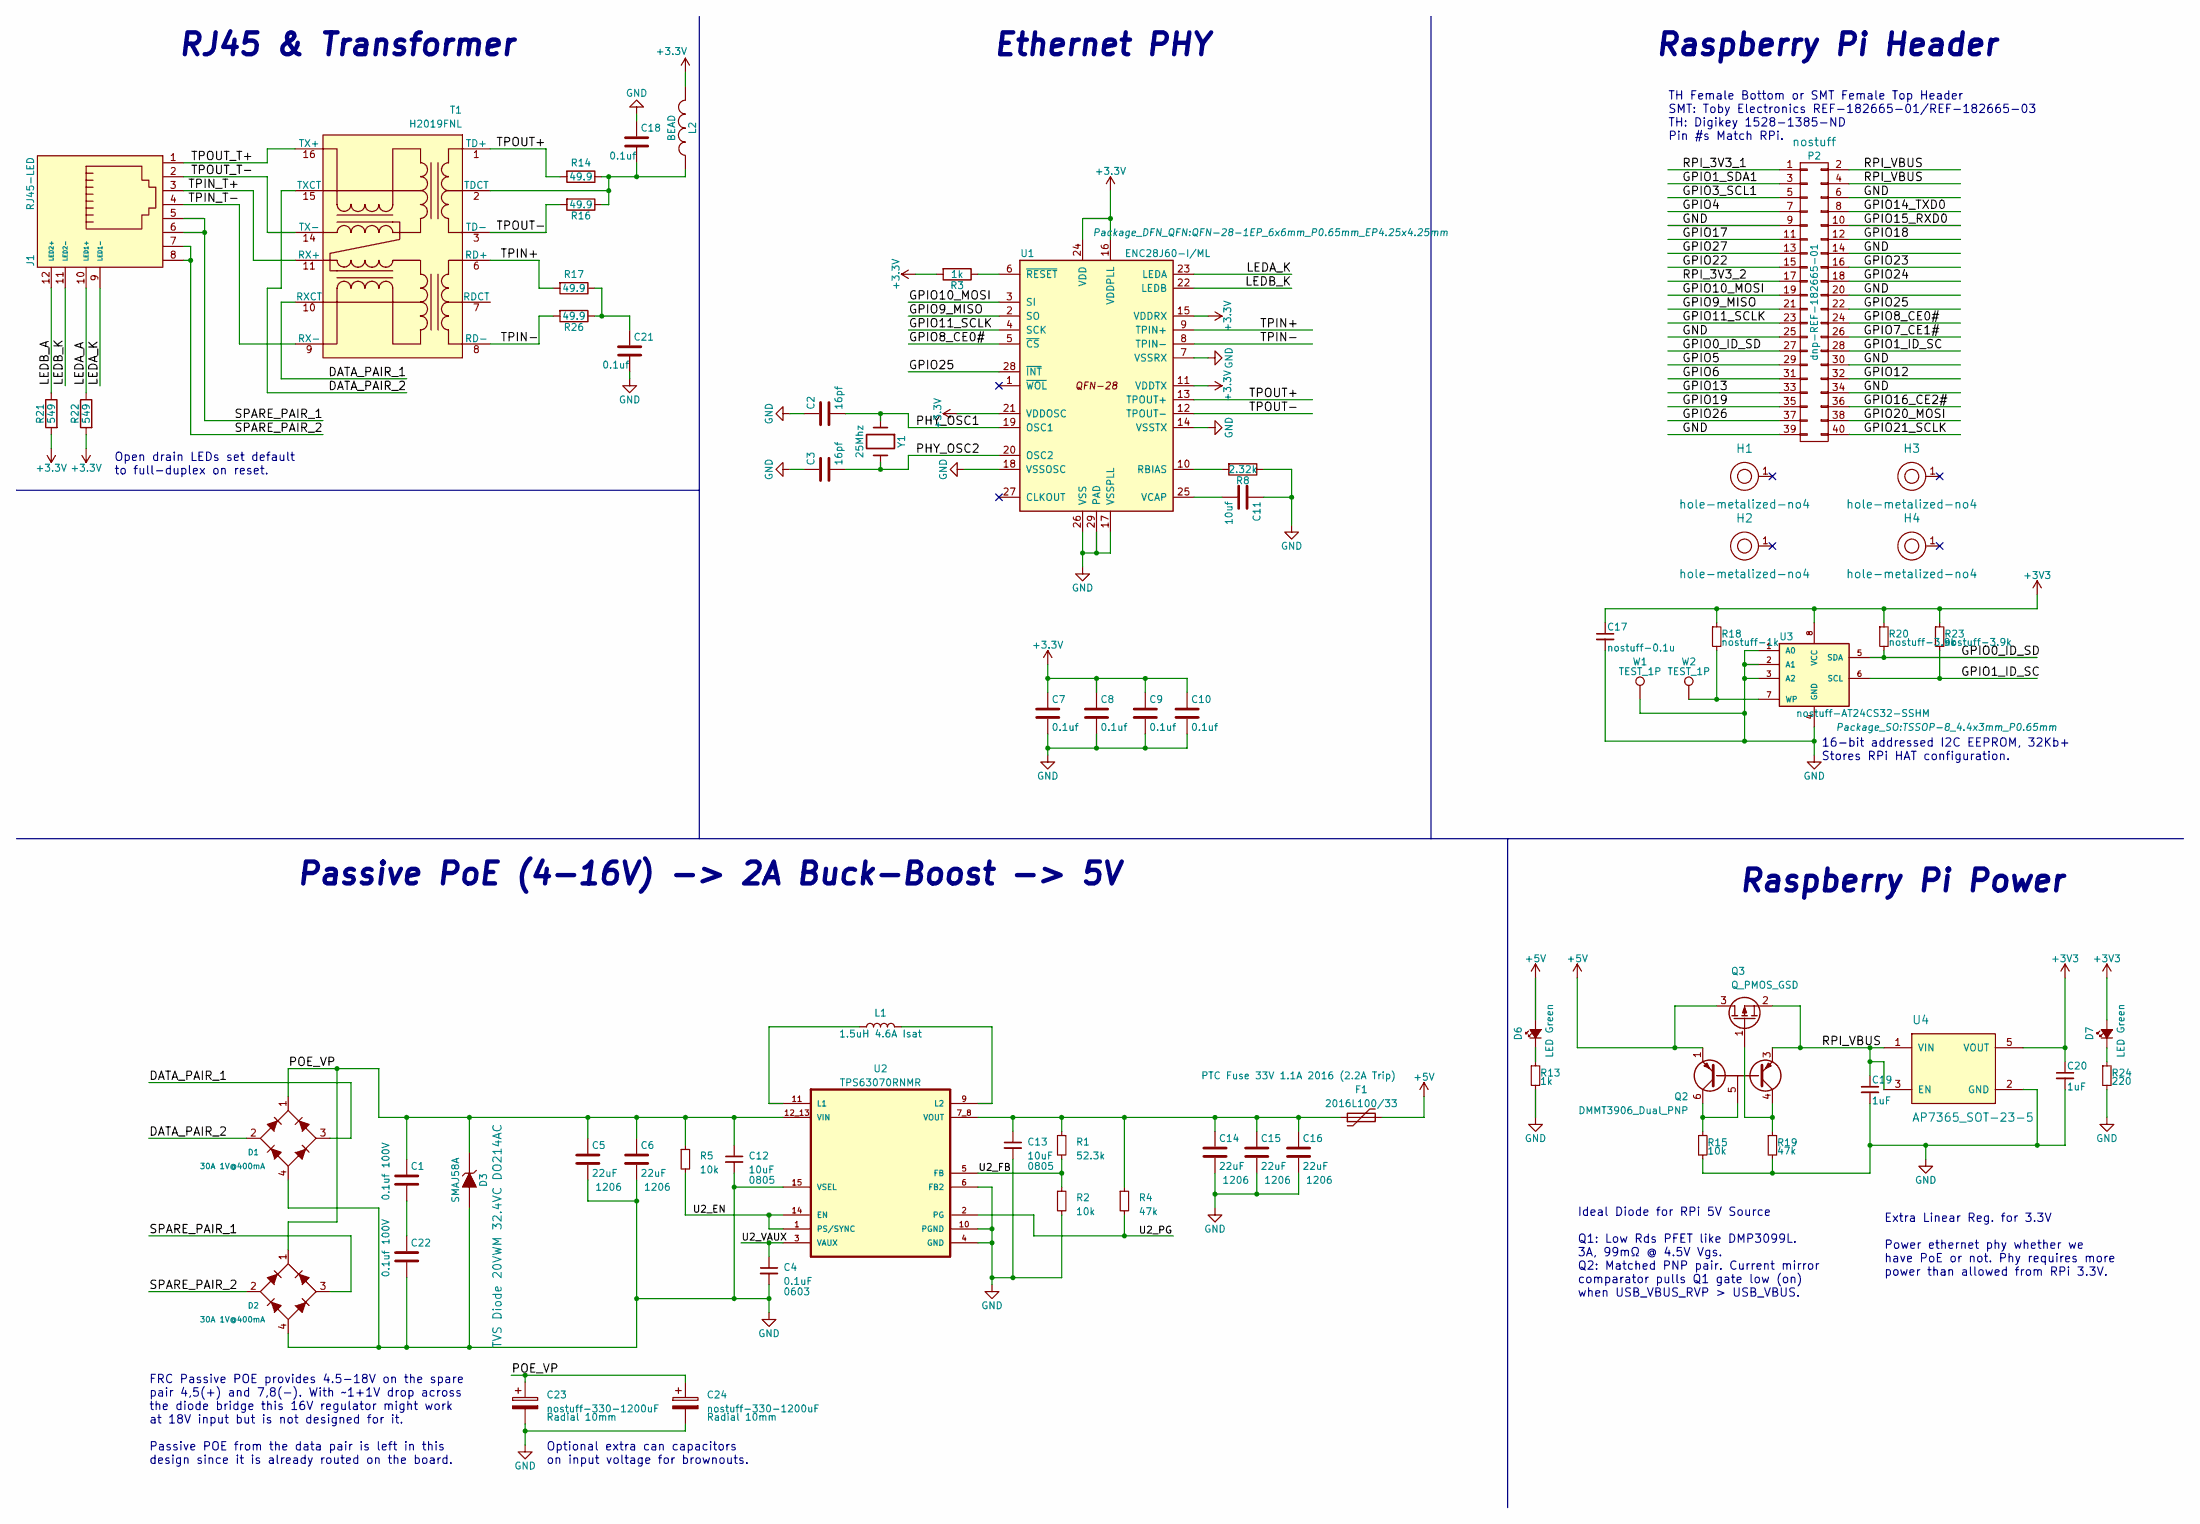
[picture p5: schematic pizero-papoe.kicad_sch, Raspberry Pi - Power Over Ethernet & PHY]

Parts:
C1, C22: 0.1uf 100V; C_0603_1608Metric; Mfg Part No CL10B104KC8NNNC; Digikey Part No 1276-6807-1-ND
C2, C3: 16pf; C_0603_1608Metric
C4: 0.1uF; C_0603_1608Metric; Mfg Part No CC0603KRX7R7BB104; LCSC C108079
C5: 22uF; C_1206_3216Metric; Mfg Part No CC1206KKX5R8BB226; LCSC C2178233
C6, C14, C15, C16: 22uF; C_1206_3216Metric
C7, C8, C9, C10, C18, C21: 0.1uf; C_0603_1608Metric
C11: 10uf; C_1206_3216Metric
C12: 10uF; C_0805_2012Metric; Mfg Part No GRT21BC71E106KE13L; LCSC C882505
C13: 10uF; C_0805_2012Metric
C17: nostuff-0.1u; C_0603_1608Metric
C19, C20: 1uF; C_0603_1608Metric
C23, C24: nostuff-330-1200uF; CP_Radial_D10.0mm_P5.00mm; Mfg Part No RNL1E122MDSASQ
D1: 30A 1V@400mA; MBS; Mfg Part No HD01-T; Digikey Part No HD01DICT-ND
D2: 30A 1V@400mA; MBS
D3: SMAJ58A; D_SMA; Mfg Part No SMAJ20A; LCSC C148209
D6, D7: LED Green; LED_0603_1608Metric; Mfg Part No LTST-C190GKT; Digikey Part No 160-1183-1-ND
F1: 2016L100/33; Mfg Part No 2016L100/33DR; LCSC C207077
H1, H2, H3, H4: hole-metalized-no4; hole-m3
J1: RJ45-LED; rj45-tyco-2-406549-7; Mfg Part No RJHSE-5081; Digikey Part No RJHSE-5081-ND
L1: 1.5uH 4.6A Isat; L_Sunlord_SWPA4030S; Mfg Part No XFL4020-152ME; JLCPCB Part # LCSC
L2: BEAD; R_0603_1608Metric; Mfg Part No BK1608HS102-T; Digikey Part No 587-1867-1-ND
P2: dnp-REF-182665-01; Pin_Header_Straight_TH-SMT-NoPaste_2x20
Q2: DMMT3906_Dual_PNP; SOT-23-6; Mfg Part No DMMT3906-7-F; Digikey Part No DMMT3906-7-FDICT-ND
Q3: Q_PMOS_GSD; SOT-23; Mfg Part No DMP3099L-7; Digikey Part No DMP3099L-7DICT-ND
R1: 52.3k; R_0603_1608Metric
R2, R5, R15: 10k; R_0603_1608Metric
R3, R13: 1k; R_0603_1608Metric
R4, R19: 47k; R_0603_1608Metric
R8: 2.32k; R_0603_1608Metric
R14, R16, R17, R26: 49.9; R_0603_1608Metric
R18: nostuff-1k; R_0603_1608Metric
R20, R23: nostuff-3.9k; R_0603_1608Metric
R21, R22: 549; R_0603_1608Metric
R24: 220; R_0603_1608Metric
T1: H2019FNL; Transformer_Pulse_H2019FNL; Mfg Part No 749013011A; Digikey Part No 732-7063-1-ND
U1: ENC28J60-I/ML; QFN-28-1EP_6x6mm_P0.65mm_EP4.25x4.25mm; Mfg Part No ENC28J60-I/ML; Digikey Part No ENC28J60-I/ML-ND
U2: TPS63070RNMR; VREG_TPS63070RNMR; Mfg Part No TPS63070RNMR; LCSC C109322
U3: nostuff-AT24CS32-SSHM; TSSOP-8_4.4x3mm_P0.65mm
U4: AP7365_SOT-23-5; SOT-23-5; Mfg Part No AP7365-33WG-7; Digikey Part No AP7365-33WG-7DICT-ND
W1, W2: TEST_1P; TestPoint_Pad_D1.0mm
Y1: 25Mhz; Crystal_SMD_5032-2Pin_5.0x3.2mm; Mouser Part No. 774-445I23D25M00000

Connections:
+5V: D6.2 (A), F1.2, Q2.1 (E1), Q3.3 (D)
/DATA_PAIR_1: D1.3 (~2), T1.10 (RXCT)
/DATA_PAIR_2: D1.2 (~1), T1.15 (TXCT)
/GPIO0_ID_SD: P2.27, R20.2, U3.5 (SDA)
/GPIO1_ID_SC: P2.28, R23.2, U3.6 (SCL)
/GPIO1_SDA1: P2.3
/GPIO3_SCL1: P2.5
/GPIO4: P2.7
/GPIO5: P2.29
/GPIO6: P2.31
/GPIO7_CE1#: P2.26
/GPIO8_CE0#: P2.24, U1.5 (~CS)
/GPIO9_MISO: P2.21, U1.2 (SO)
/GPIO10_MOSI: P2.19, U1.3 (SI)
/GPIO11_SCLK: P2.23, U1.4 (SCK)
/GPIO12: P2.32
/GPIO13: P2.33
/GPIO14_TXD0: P2.8
/GPIO15_RXD0: P2.10
/GPIO16_CE2#: P2.36
/GPIO17: P2.11
/GPIO18: P2.12
/GPIO19: P2.35
/GPIO20_MOSI: P2.38
/GPIO21_SCLK: P2.40
/GPIO22: P2.15
/GPIO23: P2.16
/GPIO24: P2.18
/GPIO25: P2.22, U1.28 (~INT)
/GPIO26: P2.37
/GPIO27: P2.13
/LEDA_A: J1.10 (LED1+), R22.1
/LEDA_K: J1.9 (LED1-), U1.23 (LEDA)
/LEDB_A: J1.12 (LED2+), R21.1
/LEDB_K: J1.11 (LED2-), U1.22 (LEDB)
/PHY_OSC1: C2.2, U1.19 (OSC1), Y1.1
/PHY_OSC2: C3.2, U1.20 (OSC2), Y1.2
/POE_VP: C1.1, C5.1, C6.1, C12.1, C23.1, C24.1, D1.1 (V+), D2.1 (V+), D3.1 (K), R5.1, U2.12_13 (VIN)
/RPI_3V3_1: P2.1
/RPI_3V3_2: P2.17
/RPI_VBUS: C19.1, P2.2, P2.4, Q2.3 (E2), Q3.2 (S), U4.1 (VIN), U4.3 (EN)
/SPARE_PAIR_1: D2.3 (~2), J1.5, J1.6
/SPARE_PAIR_2: D2.2 (~1), J1.7, J1.8
/TPIN+: R17.2, T1.6 (RD+), U1.9 (TPIN+)
/TPIN-: R26.2, T1.8 (RD-), U1.8 (TPIN-)
/TPIN_T+: J1.3, T1.11 (RX+)
/TPIN_T-: J1.4, T1.9 (RX-)
/TPOUT+: R14.2, T1.1 (TD+), U1.13 (TPOUT+)
/TPOUT-: R16.2, T1.3 (TD-), U1.12 (TPOUT-)
/TPOUT_T+: J1.1, T1.16 (TX+)
/TPOUT_T-: J1.2, T1.14 (TX-)
/U2_EN: R5.2, U2.1 (PS/SYNC), U2.14 (EN)
/U2_FB: R1.2, R2.1, U2.5 (FB)
/U2_PG: R4.2, U2.2 (PG)
/U2_VAUX: C4.1, U2.3 (VAUX)
GND: C2.1, C3.1, C4.2, C5.2, C6.2, C7.2, C8.2, C9.2, C10.2, C11.1, C12.2, C13.2, C14.2, C15.2, C16.2, C17.2, C18.1, C19.2, C20.2, C21.2, C22.2, C23.2, C24.2, D1.4 (V-), D2.4 (V-), D3.2 (A), P2.6, P2.9, P2.14, P2.20, P2.25, P2.30, P2.34, P2.39, R2.2, R8.1, R13.2, R15.2, R19.2, R24.2, U1.7 (VSSRX), U1.14 (VSSTX), U1.17 (VSSPLL), U1.18 (VSSOSC), U1.26 (VSS), U1.29 (PAD), U2.4 (GND), U2.6 (FB2), U2.10 (PGND), U2.15 (VSEL), U3.1 (A0), U3.2 (A1), U3.3 (A2), U3.4 (GND), U4.2 (GND), W1.1
unnamed: C1.2, C22.1
unnamed: C21.1, R17.1, R26.1
unnamed: D6.1 (K), R13.1
unnamed: D7.1 (K), R24.1
unnamed: Q2.5 (B), Q2.6 (C1), R15.1
unnamed: Q2.4 (C2), Q3.1 (G), R19.1
unnamed: C18.2, L2.1, R14.1, R16.1, T1.2 (TDCT)
unnamed: R8.2, U1.10 (RBIAS)
unnamed: C11.2, U1.25 (VCAP)
unnamed: R3.1, U1.6 (~RESET)
unnamed: L1.1, U2.11 (L1)
unnamed: L1.2, U2.9 (L2)
unnamed: C13.1, C14.1, C15.1, C16.1, F1.1, R1.1, R4.1, U2.7_8 (VOUT)
unnamed: R18.2, U3.7 (WP), W2.1

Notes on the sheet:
TH Female Bottom or SMT Female Top Header SMT: Toby Electronics REF-182665-01/REF-182665-03 TH: Digikey 1528-1385-ND Pin #s Match RPi.
Raspberry Pi Header
16-bit addressed I2C EEPROM, 32Kb+ Stores RPi HAT configuration.
Passive PoE (4-16V) -> 2A Buck-Boost -> 5V
Raspberry Pi Power
Ideal Diode for RPi 5V Source Q1: Low Rds PFET like DMP3099L. 3A, 99mΩ @ 4.5V Vgs. Q2: Matched PNP pair. Current mirror comparator pulls Q1 gate low (on) when USB_VBUS_RVP > USB_VBUS.
Extra Linear Reg. for 3.3V Power ethernet phy whether we have PoE or not. Phy requires more power than allowed from RPi 3.3V.
Open drain LEDs set default to full-duplex on reset.
FRC Passive POE provides 4.5-18V on the spare pair 4,5(+) and 7,8(-). With ~1+1V drop across the diode bridge this 16V regulator might work at 18V input but is not designed for it. Passive POE from the data pair is left in this design since it is already routed on the board.
RJ45 & Transformer
Optional extra can capacitors on input voltage for brownouts.
Ethernet PHY

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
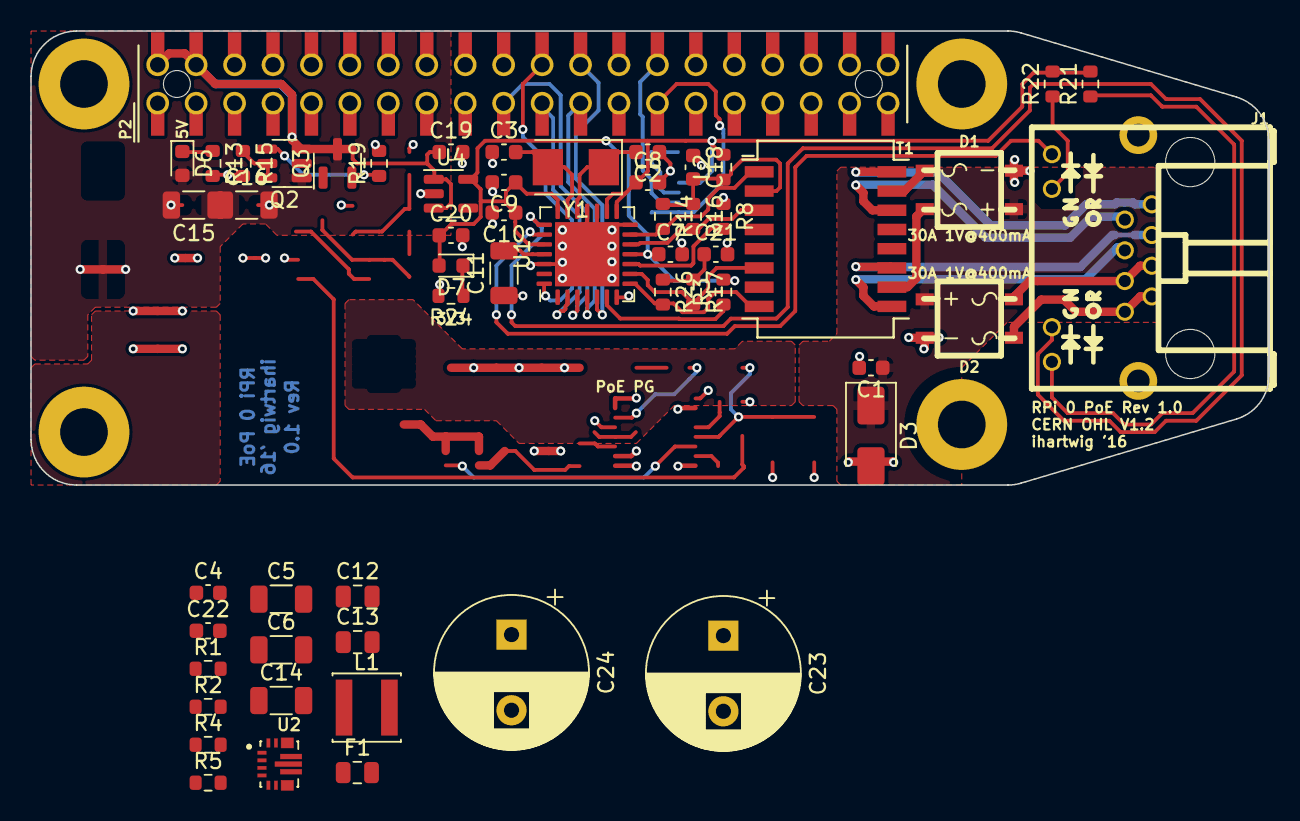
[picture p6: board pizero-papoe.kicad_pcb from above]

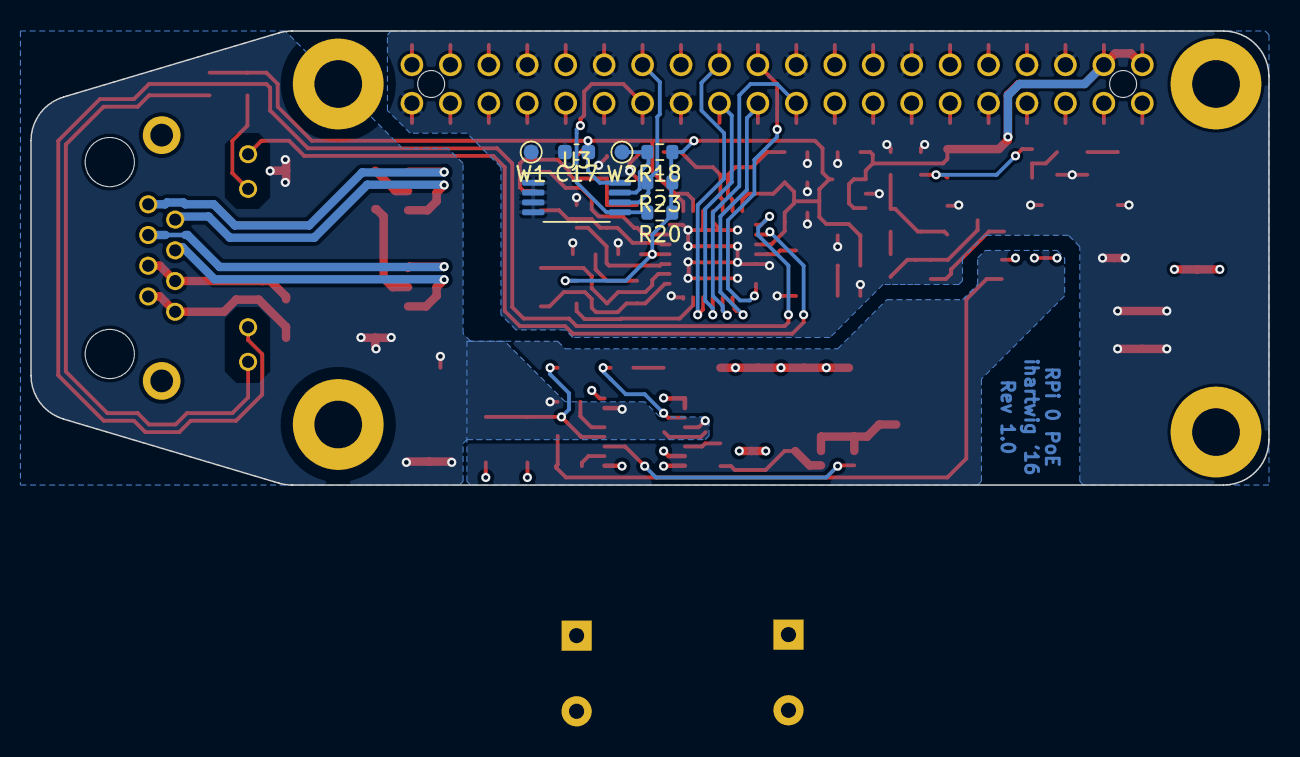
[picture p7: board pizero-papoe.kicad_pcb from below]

Board: 2 copper layers, 81.8 x 30.0 mm, 67 parts (7 on the bottom side), 48 nets.

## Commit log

2016-09-15 copy ws2812-controller as base for poe-only-top-smt variant
    [Ideal_Diode.sch, board_edge.dxf, bom.csv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]
2016-09-25 use rpi interface from ihartwig/raspberrypi-debugger and footprints from kicad 4+
    [Ideal_Diode.sch, pizero-poe.kicad_pcb, pizero-poe.sch]
2016-09-27 refresh parts on pcb and separate functional groups
    [pizero-poe.kicad_pcb]
2016-10-01 floorplan, named nets, design rules set
    [pizero-poe.kicad_pcb, pizero-poe.sch]
2016-10-05 complete routing for poe and ethernet
    * isolate to ~500Vac with .75-.8mm gaps between high and low voltage copper
    * remove extra 2x13 compatibility holes from pizero_poe_special:Pin_Header_Straight_TH-SMT-NoPaste_2x20, Pin_Header_Straight_TH-SMT_2x20 footprints
    * add insert attribute to pizero_poe_special:Crystal_Grounded_3.2x2.5, MBS, Pin_Header_Straight_TH-SMT_2x20, sod123, sod323, sod523 footprints.
    * change rpi hat eeprom power from RPI_3V3_2 to +3V3
    * calculate trace geometry for ethenet impedance control
    [pizero-poe.kicad_pcb, pizero-poe.sch]
2016-10-06 add datasheets, change eth magnetics, clean up silkscreen
    [pizero-poe.kicad_pcb, pizero-poe.sch]
2016-10-09 add part info to schematic for BOM. TODO: UPDATE LAYOUT
    [pizero-poe.csv, pizero-poe.kicad_pcb, pizero-poe.sch]
2016-10-10 fix layout for larger cap, isolation, solder mask
    * larger footprint for 470uF cap and adjust power and phy to fit
    * fix 3d model of rpi header for 20 pins
    * add soldermask expansion
    * allow soldermask tenting on ethernet phy ep
    * add gerbers
    [pizero-poe-B.Cu.gbl, pizero-poe-B.Mask.gbs, pizero-poe-B.Paste.gbp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]
2018-07-22 update readme, bom, gerbers
    [pizero-poe.csv, pizero-poe.sch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]
2024-12-02 add passive-poe-only-top-smt variant schematic
    [pizero-papoe-B_Cu.gbl, pizero-papoe-B_Mask.gbs, pizero-papoe-B_Paste.gbp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]
2024-12-10 add schematic pcb and abandonment note
